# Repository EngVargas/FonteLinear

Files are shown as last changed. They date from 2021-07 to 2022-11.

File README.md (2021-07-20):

# Fonte Linear
Projeto de uma fonte linear, com transformador, baseada em reguladores 78xx, 79xx e LM317.
<br><br><br>

Vídeos explicando o projeto (youtube) disponíveis em:

*Parte 1:* Introdução realizado no SMath (4:10): https://youtu.be/99YkMpbQ9RE

*Parte 2:* Topologia (circuito) da fonte em questão (13:12): https://youtu.be/afl0XzgpsDg

*Parte 3:* Projeto realizado no SMath (16:18): https://youtu.be/Y6MiDEMt3rU

*Parte 4:* Simulações realizadas no LTspice (9:07): https://youtu.be/Sk8upL2aWj8

*Parte 5:* Placa (*board*) realizada no KiCad (3:58): https://youtu.be/-oL63cRfRww

*Parte 6:* Corroendo a placa de fenolite (x:xx): Falta gravar.

*Parte 7:* Solda dos componentes PTH (*through-hole*) (x:xx): Falta gravar.

<br><br><br>

Playlist completa: https://www.youtube.com/playlist?list=PLbFFLnJpBtKtD-fQlKbGmZ5WMdUnZlrNB

Canal do Youtube:  https://www.youtube.com/channel/UCZTJobFHQ0Zxr3MwumCp64A

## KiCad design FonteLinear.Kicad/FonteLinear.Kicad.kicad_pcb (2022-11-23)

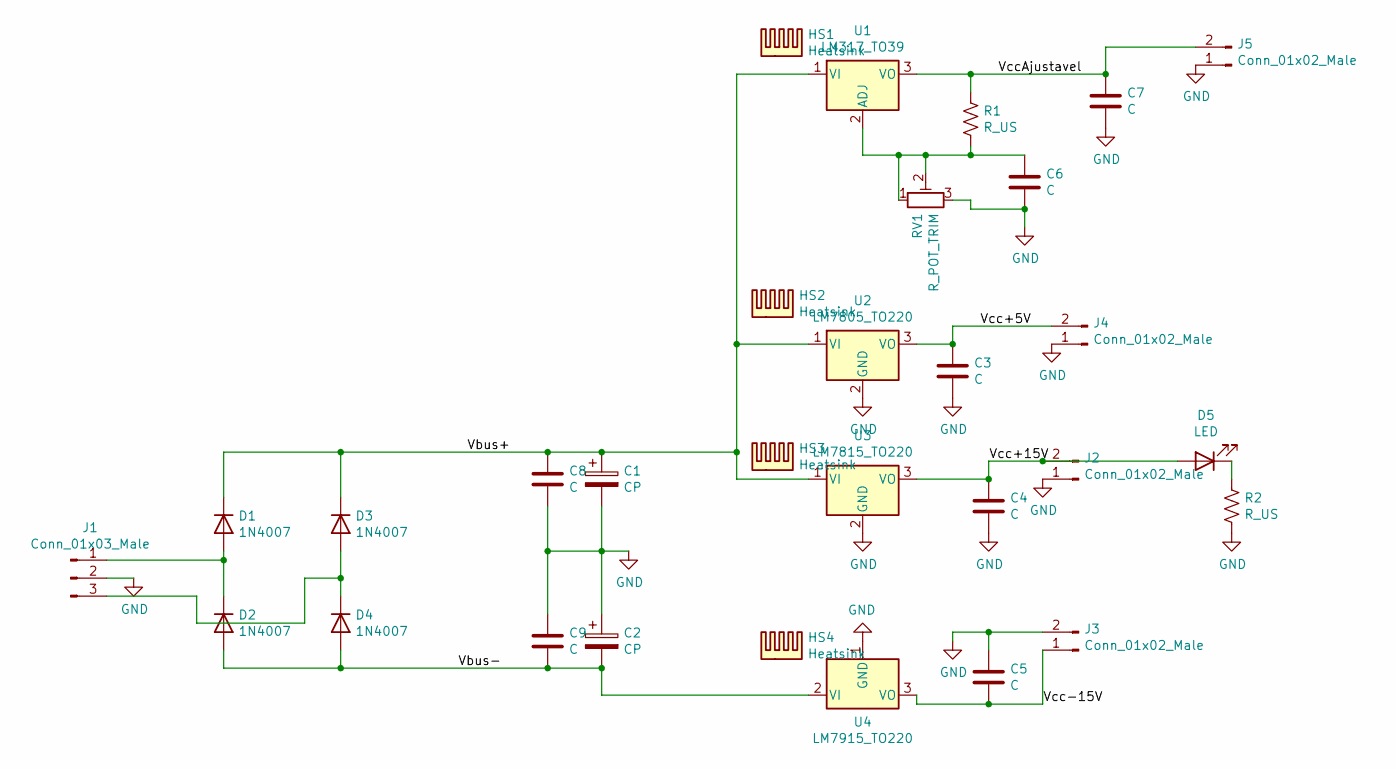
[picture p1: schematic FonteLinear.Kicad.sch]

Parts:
C1, C2: CP; CP_Radial_D16.0mm_P7.50mm
C3, C4, C5, C6, C7, C8, C9: C; C_Disc_D5.0mm_W2.5mm_P2.50mm
D1, D2, D3, D4: 1N4007; D_DO-41_SOD81_P10.16mm_Horizontal
D5: LED; LED_D5.0mm
HS1, HS2, HS3, HS4: Heatsink; Heatsink_Stonecold_HS-132_32x14mm_2xFixation1.5mm
J1: Conn_01x03_Male; PinHeader_1x03_P2.54mm_Vertical
J2, J3, J4, J5: Conn_01x02_Male; PinHeader_1x02_P2.54mm_Vertical
R1, R2: R_US; R_Axial_DIN0207_L6.3mm_D2.5mm_P7.62mm_Horizontal
RV1: R_POT_TRIM; Potentiometer_Bourns_3005_Horizontal
U1: LM317_TO39; TO-220-3_Vertical
U2: LM7805_TO220; TO-220-3_Vertical
U3: LM7815_TO220; TO-220-3_Vertical
U4: LM7915_TO220; TO-220-3_Vertical

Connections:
/Vbus+: C1.1, C8.1, D1.1 (K), D3.1 (K), U1.1 (VI), U2.1 (VI), U3.1 (VI)
/Vbus-: C2.2, C9.2, D2.2 (A), D4.2 (A), U4.2 (VI)
/Vcc+5V: C3.1, J4.2, U2.3 (VO)
/Vcc+15V: C4.1, D5.2 (A), J2.2, U3.3 (VO)
/Vcc-15V: C5.2, J3.1, U4.3 (VO)
/VccAjustavel: C7.1, J5.2, R1.1, U1.3 (VO)
GND: C1.2, C2.1, C3.2, C4.2, C5.1, C6.2, C7.2, C8.2, C9.1, J1.2, J2.1, J3.2, J4.1, J5.1, R2.2, RV1.3, U2.2 (GND), U3.2 (GND), U4.1 (GND)
unnamed: C6.1, R1.2, RV1.1, RV1.2, U1.2 (ADJ)
unnamed: D1.2 (A), D2.1 (K), J1.1
unnamed: D3.2 (A), D4.1 (K), J1.3
unnamed: D5.1 (K), R2.1

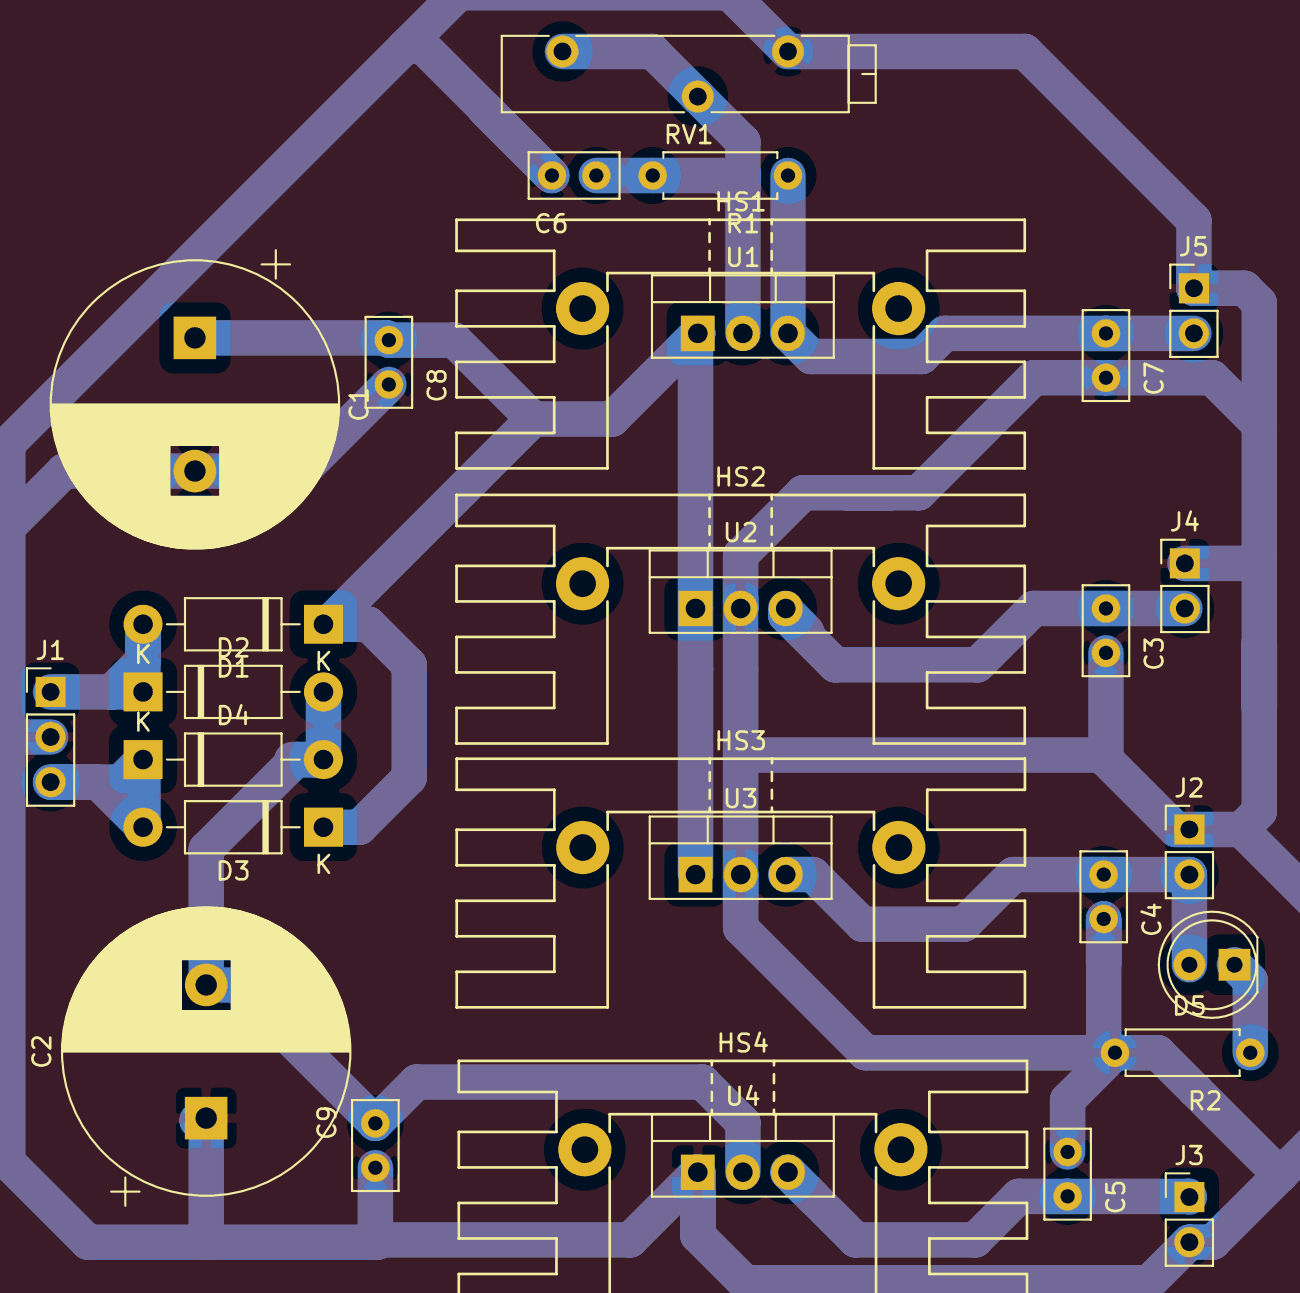
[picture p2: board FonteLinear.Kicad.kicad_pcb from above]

Board: 2 copper layers, 30 parts (0 on the bottom side), 11 nets.
